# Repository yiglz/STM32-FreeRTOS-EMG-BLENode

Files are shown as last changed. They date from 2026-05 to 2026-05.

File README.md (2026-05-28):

# STM32-FreeRTOS-EMG-BLENode
A low-power BLE node built with STM32 and FreeRTOS, featuring real-time EMG signal processing and gesture recognition via DMA-driven ADC

Raw muscle signals are noisy and microvolt-level. This project acts as a real-time biometric translation engine. It is a custom-built embedded device that captures raw biopotentials, filters out electromagnetic noise in the analog domain, analyzes muscle power via RTOS, and transmits hand gestures over Bluetooth Low Energy (BLE).

STM32_BLEEMG_PCB

---
## Used ICs
* **MCU & BLE Radio:** STM32WB55RG (Dual-Core)
* **Precision Instrumentation Amplifier:** INA333
* **Zero-Drift CMOS Op-Amps:** OPA2333
* **Ultra-Low Noise LDO:** LP5907MFX-3.3
* **Buck Converter:** AP63205WU
* **2.4 GHz Chip Antenna & Balun:** 2450AT18A100E (Antenna) & DLF162500LT-5028A1 (Balun)
---

## Analog Front-End
* The human body acts as an antenna for 50/60Hz mains noise. This design utilizes a **Right Leg Driven (RLD)** electrode network to cancel out common-mode interference.
* The raw differential signals are amplified with a **precise gain of 200** using INA333 instrumentation amplifiers.
* Before entering the ADC, the amplified signal passes through an active **2nd-Order Sallen-Key Low-Pass Filter** built with OPA2333 op-amps. Tuned to a cut-off frequency of exactly **~479 Hz**.
* The 2.4 GHz RF trace is **impedance-matched** using a DLF162500LT balun into a 2450AT18A100E chip antenna. To prevent digital switching noise from corrupting the microvolt analog signals, the analog front-end is powered by a dedicated LP5907 3.3V **ultra-low-noise LDO**.

---

## Firmware
To save energy, the system defaults to a **deep hardware sleep mode**.

* The ADC continuously captures 3 analog channels (EMG 1, EMG 2, Battery Sense). The DMA streams this incoming data into a **120-item memory buffer** without CPU intervention.
* The `vSignalTask` executes a **absolute-value averaging algorithm**. This extracts muscle power in microseconds.
* The `vGestureTask` evaluates the signals against thresholds to classify states utilizing **precise RTOS tick timing**. The system updates the BLE characteristics *only* when a definitive gesture state change is detected. By leveraging the BLE **Slave Latency** parameter, the underlying RF radio skips unnecessary connection intervals and **remains in deep sleep** during idle periods.

---

## Electrode Placement

* **Channel 1 (Flexor Group - Wrist In):** Place the active differential electrodes over the **Flexor Carpi Radialis** (inner forearm).
* **Channel 2 (Extensor Group - Wrist Out):** Place the active differential electrodes over the **Extensor Digitorum** or **Extensor Carpi Radialis** (outer forearm).
* **RLD Reference:** The Right Leg Drive (Reference) electrode must be placed on an electrically neutral area with minimal underlying muscle activity. The **elbow** or the **wrist bone** are the optimal targets.

## This Repository Contains
* **Firmware (`Core/` & `STM32_WPAN/`)
* **`.ioc` File
* **Schematic PDF
* **Gerber and Drill Files

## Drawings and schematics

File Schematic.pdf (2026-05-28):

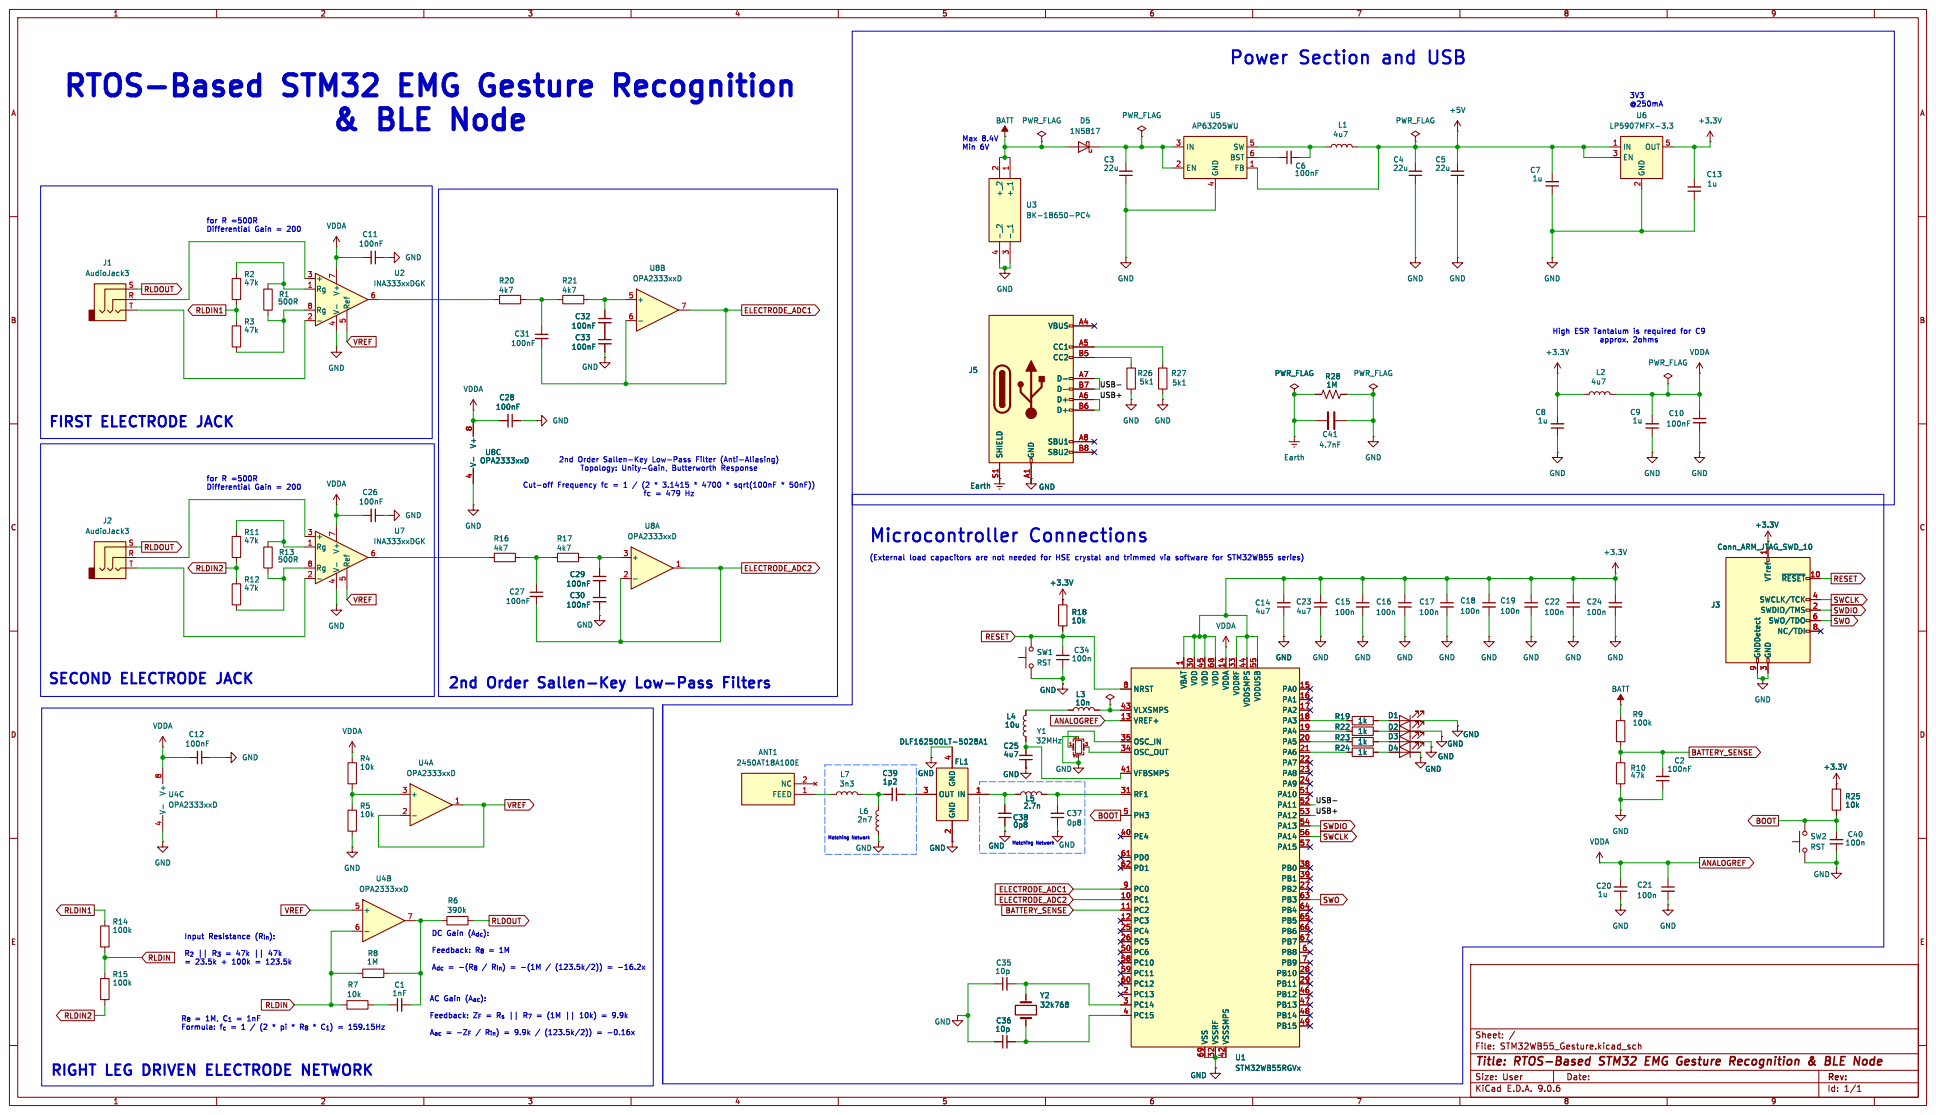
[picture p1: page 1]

3V3 @250mA Power Section and USB

1 VDD 30 VDD 45 VSS 69 VDD 68 VSSRF 32 VDDA 14 VSSSMPS 42 VDDRF 33 VDDSMPS 44 VDDUSB 55 PA0 15 PA1 16 PA2 17 PA3 18 PA4 19 PA5 20 PA6 21 PA7 22 PA8 23 PA9 24 PA10 51 PA11 52 PA12 53 PA13 54 PA14 56 PA15 57 PB0 38 PB1 39 PB2 27 PB3 63 PB4 64 PB5 65 PB6 66 PB7 67 PB8 6 PB9 7 PB10 28 PB11 29 PB12 46 PB13 47 PB14 48 PB15 49 U1STM32WB55RGVx

1 VDD 30 VDD 45 VSS 69 VDD 68 VSSRF 32 VDDA 14 VSSSMPS 42 VDDRF 33 VDDSMPS 44 VDDUSB 55 PA0 15 PA1 16 PA2 17 PA3 18 PA4 19 PA5 20 PA6 21 PA7 22 PA8 23 PA9 24 PA10 51 PA11 52 PA12 53 PA13 54 PA14 56 PA15 57 PB0 38 PB1 39 PB2 27 PB3 63 PB4 64 PB5 65 PB6 66 PB7 67 PB8 6 PB9 7 PB10 28 PB11 29 PB12 46 PB13 47 PB14 48 PB15 49 GND

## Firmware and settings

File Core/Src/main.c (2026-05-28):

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
/* Includes ------------------------------------------------------------------*/

#include "main.h"
#include "usb_device.h"
#include "FreeRTOS.h"
#include "task.h"
#include "queue.h"
#include <stdio.h>

/* USER CODE BEGIN PTD */

typedef struct {
    uint16_t Electrode1_Power;
    uint16_t Electrode2_Power;
    uint16_t Battery;
} Data_t;

/* USER CODE END PTD */

/* USER CODE BEGIN PD */

#define THRESHOLD            250
#define IDLE                 30
#define DOUBLE_FLEXTIMEOUT   400   
#define RMS_WINDOW           200
#define BUFFER_SIZE          120

/* USER CODE END PD */


ADC_HandleTypeDef hadc1;

DMA_HandleTypeDef hdma_adc1;

IPCC_HandleTypeDef hipcc;

RTC_HandleTypeDef hrtc;

TIM_HandleTypeDef htim1;

/* USER CODE BEGIN PV */

Data_t data;
uint16_t adc_buffer[BUFFER_SIZE];
TaskHandle_t SignalTaskHandle;
TaskHandle_t GestureHandle;

/* USER CODE END PV */

void SystemClock_Config(void);
void PeriphCommonClock_Config(void);
static void MX_GPIO_Init(void);
static void MX_DMA_Init(void);
static void MX_ADC1_Init(void);
static void MX_IPCC_Init(void);
static void MX_RTC_Init(void);
static void MX_TIM1_Init(void);
static void MX_RF_Init(void);
/* USER CODE BEGIN PFP */

void vSignalTask(void *pvParameters);
void vGestureTask(void *pvParameters);

extern void Send_Gesture_To_BLE(uint8_t gesture);
extern void Send_Battery_To_BLE(uint8_t battery_level);

/* USER CODE END PFP */

/* USER CODE BEGIN 0 */

// =========================================================================
// DMA INTERRUPT CALLBACK
// =========================================================================


void HAL_ADC_ConvCpltCallback(ADC_HandleTypeDef* hadc) {
    BaseType_t xHigherPriorityTaskWoken = pdFALSE;
    vTaskNotifyGiveFromISR(SignalTaskHandle, &xHigherPriorityTaskWoken);
    portYIELD_FROM_ISR(xHigherPriorityTaskWoken);
}

/* USER CODE END 0 */

/**
  * @brief  The application entry point.
  * @retval int
  */
int main(void)
{
  /* MCU Configuration--------------------------------------------------------*/

  HAL_Init();
  MX_APPE_Config();

  /* Configure the system clock */
  SystemClock_Config();

  /* Configure the peripherals common clocks */
  PeriphCommonClock_Config();

  /* IPCC initialisation */
  MX_IPCC_Init();

  /* Initialize all configured peripherals */
  MX_GPIO_Init();
  MX_DMA_Init();
  MX_ADC1_Init();
  MX_RTC_Init();
  MX_TIM1_Init();
  MX_USB_Device_Init();
  MX_RF_Init();

  /* USER CODE BEGIN 2 */

  HAL_ADC_Start_DMA(&hadc1, (uint32_t*)adc_buffer, BUFFER_SIZE);
  xTaskCreate(vSignalTask, "SignalTask", 256, NULL, 3, &SignalTaskHandle);
  xTaskCreate(vGestureTask, "GestureTask", 256, NULL, 2, &GestureHandle);

  vTaskStartScheduler();

  /* USER CODE END 2 */

  /* Init code for STM32_WPAN */
  MX_APPE_Init();

  /* Infinite loop */
  /* USER CODE BEGIN WHILE */
  while (1)
  {
    /* USER CODE END WHILE */
    MX_APPE_Process();

    /* USER CODE BEGIN 3 */
  }
  /* USER CODE END 3 */
}

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
/* USER CODE BEGIN 4 */

// =========================================================================
// TASK 1: SIGNAL PROCESSING ENGINE
// =========================================================================
void vSignalTask(void *pvParameters) {
    uint8_t previousBattery = 0;
    extern uint8_t BleConnected;

    while(1) {

        ulTaskNotifyTake(pdTRUE, portMAX_DELAY);

        uint32_t total1 = 0;
        uint32_t total2 = 0;

        for(uint16_t i = 0; i < BUFFER_SIZE; i += 3) {
            /* Remove DC Offset (Assuming 12-bit ADC, Vref/2 = 2048) */
            int32_t raw1 = (int32_t)adc_buffer[i] - 2048;
            int32_t raw2 = (int32_t)adc_buffer[i+1] - 2048;

            if(raw1 < 0) { raw1 = -raw1; }
            if(raw2 < 0) { raw2 = -raw2; }

            total1 += raw1;
            total2 += raw2;
        }

        /* Calculate average power over the window */
        data.Electrode1_Power = (uint16_t)(total1 / 40);
        data.Electrode2_Power = (uint16_t)(total2 / 40);

        /* Battery Level Calculation via Voltage Divider Formula */
        uint16_t raw_battery = adc_buffer[2];
        float v_battery = raw_battery * 0.0025204f;
        int8_t battery_percentage = (int8_t)((v_battery - 6.4f) * 50.0f);

        /* Clamp percentage between 0 and 100 */
        if (battery_percentage > 100) battery_percentage = 100;
        if (battery_percentage < 0)   battery_percentage = 0;

        uint8_t currentBattery = (uint8_t)battery_percentage;
        data.Battery = currentBattery;

        /*Only send if battery level changes */
        if (BleConnected == 1 && currentBattery != previousBattery) {
            Send_Battery_To_BLE(currentBattery);
            previousBattery = currentBattery;
        }
    }
}

// =========================================================================
// TASK 2: GESTURE DECISION & BLE COMMUNICATION
// =========================================================================
void vGestureTask(void *pvParameters) {
    uint32_t lastFistReleaseTime = 0;
    uint8_t currentGesture = 0;
    uint8_t previousGesture = 0;

    extern uint8_t BleConnected;

    while(1) {
        uint16_t power1 = data.Electrode1_Power;
        uint16_t power2 = data.Electrode2_Power;
        uint32_t current_tick = xTaskGetTickCount();

        // --- 1. GESTURE: WRIST IN ---
        if (power1 > THRESHOLD && power2 < IDLE) {
            HAL_GPIO_WritePin(GPIOA, GPIO_PIN_3, GPIO_PIN_SET);
            HAL_GPIO_WritePin(GPIOA, GPIO_PIN_4, GPIO_PIN_RESET);
            HAL_GPIO_WritePin(GPIOA, GPIO_PIN_5, GPIO_PIN_RESET);
            HAL_GPIO_WritePin(GPIOA, GPIO_PIN_6, GPIO_PIN_RESET);
            currentGesture = 1;
        }
        // --- 2. GESTURE: WRIST OUT ---
        else if (power1 < IDLE && power2 > THRESHOLD) {
            HAL_GPIO_WritePin(GPIOA, GPIO_PIN_3, GPIO_PIN_RESET);
            HAL_GPIO_WritePin(GPIOA, GPIO_PIN_4, GPIO_PIN_SET);
            HAL_GPIO_WritePin(GPIOA, GPIO_PIN_5, GPIO_PIN_RESET);
            HAL_GPIO_WritePin(GPIOA, GPIO_PIN_6, GPIO_PIN_RESET);
            currentGesture = 2;
        }
        // --- 3 & 4. GESTURE: SINGLE FIST / DOUBLE FIST ---
        else if (power1 > THRESHOLD && power2 > THRESHOLD) {

            if (currentGesture != 3 && currentGesture != 4) {
                if ((current_tick - lastFistReleaseTime) <= pdMS_TO_TICKS(DOUBLE_FLEXTIMEOUT)) {
                    currentGesture = 4; // Double Fist registered
                } else {
                    currentGesture = 3; // Single Fist registered
                }
            }

            HAL_GPIO_WritePin(GPIOA, GPIO_PIN_3, GPIO_PIN_RESET);
            HAL_GPIO_WritePin(GPIOA, GPIO_PIN_4, GPIO_PIN_RESET);

            /* Update status LEDs */
            if (currentGesture == 3) {
                HAL_GPIO_WritePin(GPIOA, GPIO_PIN_5, GPIO_PIN_SET);
                HAL_GPIO_WritePin(GPIOA, GPIO_PIN_6, GPIO_PIN_RESET);
            } else if (currentGesture == 4) {
                HAL_GPIO_WritePin(GPIOA, GPIO_PIN_5, GPIO_PIN_RESET);
                HAL_GPIO_WritePin(GPIOA, GPIO_PIN_6, GPIO_PIN_SET);
            }
        }
        // --- 0. GESTURE: IDLE  ---
        else if (power1 < IDLE && power2 < IDLE) {

            if (currentGesture == 3 || currentGesture == 4) {
                lastFistReleaseTime = current_tick;
            }

            /* Clear all LEDs */
            HAL_GPIO_WritePin(GPIOA, GPIO_PIN_3, GPIO_PIN_RESET);
            HAL_GPIO_WritePin(GPIOA, GPIO_PIN_4, GPIO_PIN_RESET);
            HAL_GPIO_WritePin(GPIOA, GPIO_PIN_5, GPIO_PIN_RESET);
            HAL_GPIO_WritePin(GPIOA, GPIO_PIN_6, GPIO_PIN_RESET);
            currentGesture = 0;
        }

        /*Only send when the gesture changes */
        if (BleConnected == 1 && currentGesture != previousGesture) {
            Send_Gesture_To_BLE(currentGesture);
            previousGesture = currentGesture;
        }

        vTaskDelay(pdMS_TO_TICKS(10));
    }
}

/* USER CODE END 4 */

/**
  * @brief  Period elapsed callback in non blocking mode
  * @note   This function is called  when TIM17 interrupt took place, inside
  * HAL_TIM_IRQHandler(). It makes a direct call to HAL_IncTick() to increment
  * a global variable "uwTick" used as application time base.
  * @param  htim : TIM handle
  * @retval None
  */
void HAL_TIM_PeriodElapsedCallback(TIM_HandleTypeDef *htim)
{
  if (htim->Instance == TIM17)
  {
    HAL_IncTick();
  }
}

/**
  * @brief  This function is executed in case of error occurrence.
  * @retval None
  */
void Error_Handler(void)
{
  /* USER CODE BEGIN Error_Handler_Debug */
  __disable_irq();
  while (1)
  {
  }
  /* USER CODE END Error_Handler_Debug */
}
#ifdef USE_FULL_ASSERT
/**
  * @brief  Reports the name of the source file and the source line number
  * where the assert_param error has occurred.
  * @param  file: pointer to the source file name
  * @param  line: assert_param error line source number
  * @retval None
  */
void assert_failed(uint8_t *file, uint32_t line)
{
}
#endif /* USE_FULL_ASSERT */

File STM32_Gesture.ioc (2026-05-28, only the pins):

Mcu.UserName=STM32WB55RGVx
PA11.Signal=USB_DM
PA12.Signal=USB_DP
PA13.Signal=SYS_JTMS-SWDIO
PA14.Signal=SYS_JTCK-SWCLK
PA3.Signal=GPIO_Output
PA4.Signal=GPIO_Output
PA5.Signal=GPIO_Output
PA6.Signal=GPIO_Output
PB3.Signal=SYS_JTDO-SWO
PC0.Signal=ADCx_IN1
PC1.Signal=ADCx_IN2
PC14-OSC32_IN.Signal=RCC_OSC32_IN
PC15-OSC32_OUT.Signal=RCC_OSC32_OUT
PC2.Signal=ADCx_IN3

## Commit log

2026-05-28 Files are added
    [STM32WB55_Gesture-B_Cu.gbr, STM32WB55_Gesture-B_Mask.gbr, STM32WB55_Gesture-B_Paste.gbr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]
2026-05-28 Threshold values are fixed
    [main.c]
2026-05-28 Add electrode placement section to README

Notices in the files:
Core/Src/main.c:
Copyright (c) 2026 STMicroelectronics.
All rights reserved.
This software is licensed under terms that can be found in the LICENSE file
